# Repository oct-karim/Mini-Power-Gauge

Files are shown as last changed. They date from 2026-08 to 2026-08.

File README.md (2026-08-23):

<div align="center">

#  USB-C PCB Power Gauge

A simple PCB, functional and efficient. For monitoring current, voltage and power.







</div>

##  Overview

This simple power gauge, controlled by the ATmega328P microcontroller has a voltage range of 0-36V and a current range of 0-3A. 
The footprints have been chosen to be easy to solder. And the components are widely available.

## Features
-**Range** 0/36V & 0/3.5A    
-**16x2 Display**   
-**Sleep Mode**: Consumes less energy after 30s without mesuring voltage    
-**Warning LED**: Inform the user that the mesurements are reaching the max or a activated failsafe    
-**LCD Ping**: checks if the display is alive or faulty connection  
-**AVR Watchdog**: prevents the microcontroller to freeze for more than 2 sec    
-**I2C Failsafe**: checks if the  I2C communication is good to go    
-**Over range Failsafe**: if the mesurements are more than 36V or 3.5A it shuts down the sensor.    

##  Hardware Overview

| Component | Function |
| :--- | :--- |
| **ATmega328p** | Microcontroller handling data and display. |
| **INA226** | I2C current and power sensor. |
| **HY1602E** | Standard 16x2 character LCD display. |
| **PCF8574AT** | I2C expander to drive the LCD using less pins. |
| **USB-C Port** | Power input. |
| **ICSP Socket** | Firmware upload. |

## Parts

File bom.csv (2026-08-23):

Designator | Footprint | Quantity | Value | LCSC Part #
C1, C2, C3, C7, C8, C9 | 1210 | 6 | 100n
C4, C6 | 1210 | 2 | 22p
C5 | 1210 | 1 | 10µ
D1 | 1206 | 1 | RED
D2 | 1206 | 1 | GREEN
D3 | 1206 | 1 | BLUE
D4 | D_SMA | 1 | SMAJ5.0A
DS1 | WC1602A | 1 | HY1602E
FB1 | Ferrite_1210_3225Metric_Pad1.42x2.65mm_BigPads | 1 | 300Ω@100MHz
J1 | USB_C_Receptacle_GCT_USB4125-xx-x-0190_6P_TopMnt_Horizontal | 1 | USB_C_Receptacle_PowerOnly_6P
J2 | PinSocket_1x06_P2.54mm_Vertical | 1 | Conn_01x06_Socket
J3, J4 | ScrewTerminal_1x02_P3.5mm_Horizontal_Black | 2 | 3.5mm
J5 | PinSocket_1x16_P2.54mm_Vertical | 1 | Conn_01x16_Socket
Q1 | TO-92_Inline_Wide_EBC | 1 | 2N3904
R1, R2 | 1210 | 2 | 5.1K
R10, R9 | 1210 | 2 | 1k
R11 | R_Shunt_Ohmite_LVK12 | 1 | 0,02
R3 | 1210 | 1 | 10k
R4, R5, R6 | 1210 | 3 | 470
R7, R8 | 1210 | 2 | 4.7k
U1 | TQFP-32_7x7mm_P0.8mm | 1 | ATmega328P-A
U2 | SOIC-16W_7.5x10.3mm_P1.27mm | 1 | PCF8574AT
U3 | VSSOP-10_3x3mm_P0.5mm | 1 | INA226
X1 | Crystal_SMD_2012-2Pin_2.0x1.2mm_HandSoldering | 1 | 16MHz

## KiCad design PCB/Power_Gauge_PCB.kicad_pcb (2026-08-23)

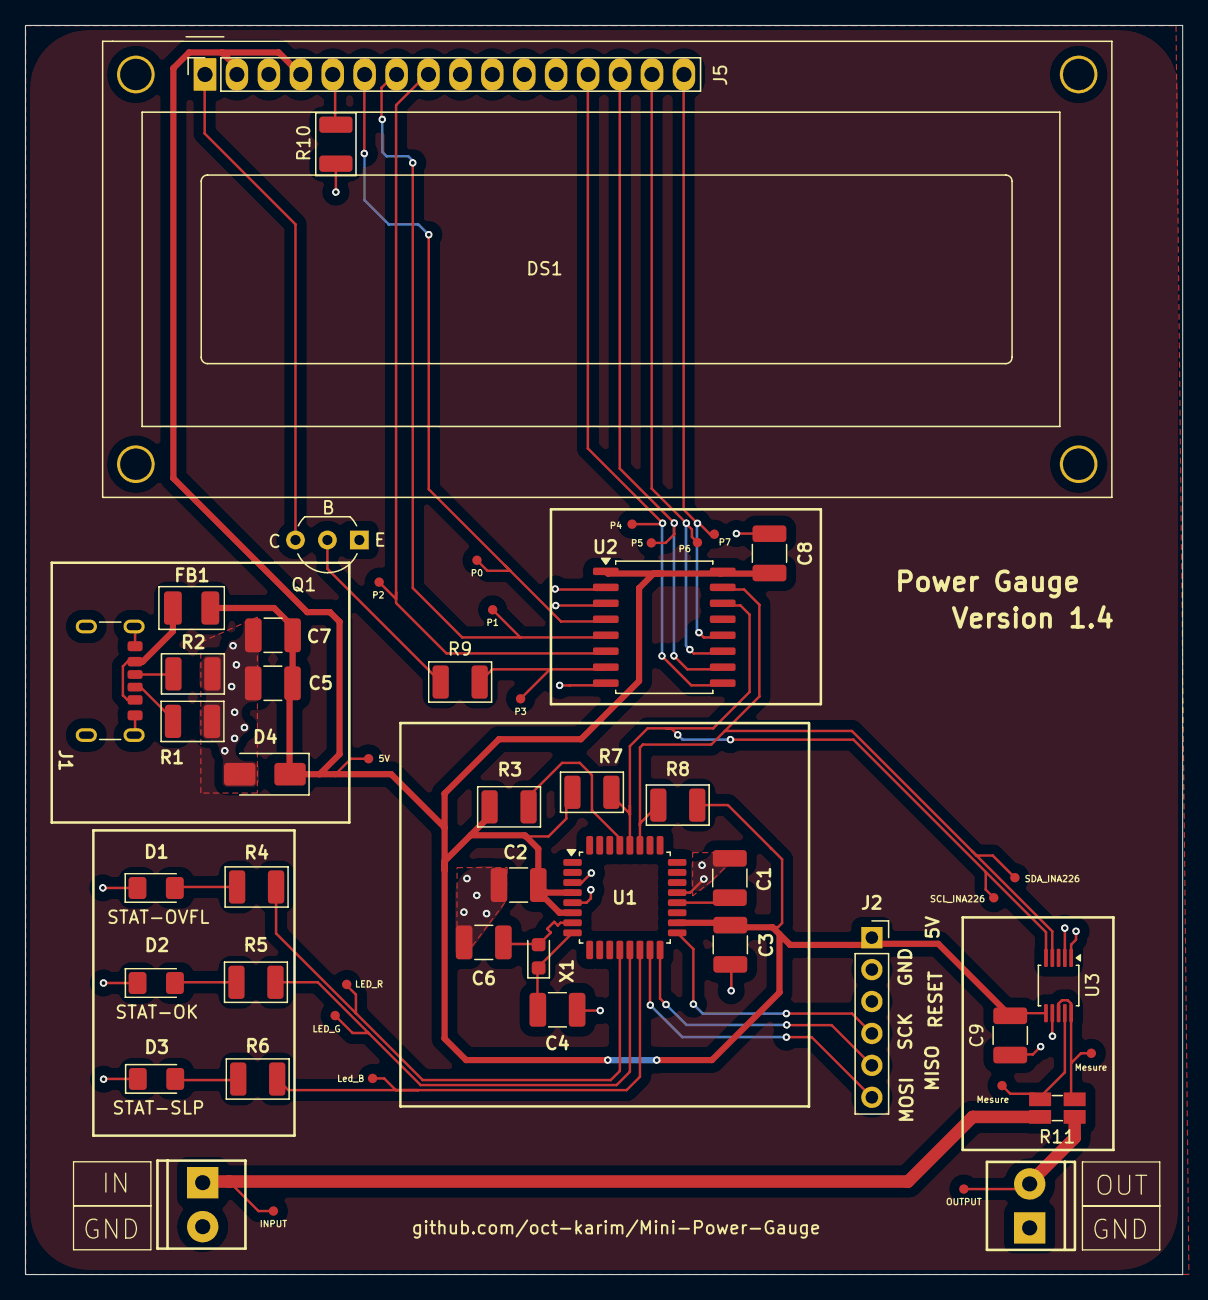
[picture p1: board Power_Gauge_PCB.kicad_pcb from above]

Board: 2 copper layers, 92.0 x 99.4 mm, 54 parts (0 on the bottom side), 35 nets.

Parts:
C1, C2, C3, C7, C8, C9: 100n; C_1210_3225Metric_Pad1.33x2.70mm_HandSolder
C4, C6: 22p; C_1210_3225Metric_Pad1.33x2.70mm_HandSolder
C5: 10µ; C_1210_3225Metric_Pad1.33x2.70mm_HandSolder
D1: RED; LED_1206_3216Metric_Pad1.42x1.75mm_HandSolder
D2: GREEN; LED_1206_3216Metric_Pad1.42x1.75mm_HandSolder
D3: BLUE; LED_1206_3216Metric_Pad1.42x1.75mm_HandSolder
D4: SMAJ5.0A; D_SMA
DS1: HY1602E; WC1602A
FB1: 300Ω@100MHz; Ferrite_1210_3225Metric_Pad1.42x2.65mm_BigPads
J1: USB_C_Receptacle_PowerOnly_6P; USB_C_Receptacle_GCT_USB4125-xx-x-0190_6P_TopMnt_Horizontal
J2: Conn_01x06_Socket; PinSocket_1x06_P2.54mm_Vertical
J3, J4: 3.5mm; ScrewTerminal_1x02_P3.5mm_Horizontal_Black
J5: Conn_01x16_Socket; PinSocket_1x16_P2.54mm_Vertical
Q1: 2N3904; TO-92_Inline_Wide_EBC
R1, R2: 5.1K; R_1210_3225Metric_Pad1.30x2.65mm
R3: 10k; R_1210_3225Metric_Pad1.30x2.65mm
R4, R5, R6: 470; R_1210_3225Metric_Pad1.30x2.65mm
R7, R8: 4.7k; R_1210_3225Metric_Pad1.30x2.65mm
R9, R10: 1k; R_1210_3225Metric_Pad1.30x2.65mm
R11: 0,02; R_Shunt_Ohmite_LVK12
TP1: LED_R; TestPoint-0.75mm
TP2: LED_G; TestPoint-0.75mm
TP3: Led_B; TestPoint-0.75mm
TP4: SCL_INA226; TestPoint-0.75mm
TP5: SDA_INA226; TestPoint-0.75mm
TP6: 5V; TestPoint-0.75mm
TP7: INPUT; TestPoint-0.75mm
TP8: OUTPUT; TestPoint-0.75mm
TP9: P1; TestPoint-0.75mm
TP10: P3; TestPoint-0.75mm
TP11: P5; TestPoint-0.75mm
TP12: P7; TestPoint-0.75mm
TP13: P0; TestPoint-0.75mm
TP14: P2; TestPoint-0.75mm
TP15: P4; TestPoint-0.75mm
TP16: P6; TestPoint-0.75mm
TP17, TP18: Mesure; TestPoint-0.75mm
U1: ATmega328P-A; TQFP-32_7x7mm_P0.8mm
U2: PCF8574AT; SOIC-16W_7.5x10.3mm_P1.27mm
U3: INA226; VSSOP-10_3x3mm_P0.5mm
X1: 16MHz; Crystal_SMD_2012-2Pin_2.0x1.2mm_HandSoldering

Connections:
5V: C2.2, C3.2, C5.1, C7.2, C8.2, C9.2, D4.1 (A1), DS1.2 (LEDA), DS1.4 (VDD), FB1.2, J2.1, J5.2, J5.4, R3.1, R7.2, R8.2, TP6.1 (1_1), U1.4 (VCC), U1.6 (VCC), U1.18 (AVCC), U2.1 (A0), U2.16 (VDD), U3.6 (VS)
/CONN_DISPLAY1: DS1.5 (Vo), J5.5, R10.2
/CONN_DISPLAY2: DS1.1 (LEDK), J5.1, Q1.3 (C)
GND: C1.1, C2.1, C3.1, C4.1, C5.2, C6.1, C7.1, C8.1, C9.1, D1.1 (K), D2.1 (K), D3.1 (K), D4.2 (A2), DS1.3 (VSS), J1.A12 (GND), J1.B12 (GND), J1.S1 (SHIELD), J2.2, J3.2, J4.1, J5.3, Q1.1 (E), R1.1, R2.2, R10.1, U1.3 (GND), U1.5 (GND), U1.21 (GND), U2.2 (A1), U2.3 (A2), U2.8 (GND), U3.1 (A1), U3.2 (A0), U3.7 (GND)
INPUT: J3.1, R11.1, TP7.1 (1_1)
MISO: J2.5, U1.16 (PB4)
MOSI: J2.6, U1.15 (PB3)
unnamed: D1.2 (A), R4.1
unnamed: D2.2 (A), R5.1
unnamed: D3.2 (A), R6.1
unnamed: FB1.1, J1.A9 (VBUS), J1.B9 (VBUS)
unnamed: J1.A5 (CC1), R2.1
unnamed: J1.B5 (CC2), R1.2
unnamed: Q1.2 (B), R9.1
unnamed: C1.2, U1.20 (AREF)
unnamed: R4.2, TP1.1 (1_1), U1.12 (PB0)
unnamed: R5.2, TP2.1 (1_1), U1.13 (PB1)
unnamed: R6.2, TP3.1 (1_1), U1.14 (PB2)
unnamed: C6.2, U1.7 (XTAL1/PB6), X1.2
unnamed: C4.2, U1.8 (XTAL2/PB7), X1.1
unnamed: R11.3, TP17.1 (1_1), U3.8 (Vbus), U3.10 (Vin+)
unnamed: R11.2, TP18.1 (1_1), U3.9 (Vin-)
OUTPUT: J4.2, R11.4, TP8.1 (1_1)
P0: DS1.6 (RS), J5.6, TP13.1 (1_1), U2.4 (P0)
P1: DS1.7 (R/~W), J5.7, TP9.1 (1_1), U2.5 (P1)
P2: DS1.8 (E), J5.8, TP14.1 (1_1), U2.6 (P2)
P3: R9.2, TP10.1 (1_1), U2.7 (P3)
P4: DS1.13 (DB4), J5.13, TP15.1 (1_1), U2.9 (P4)
P5: DS1.14 (DB5), J5.14, TP11.1 (1_1), U2.10 (P5)
P6: DS1.15 (DB6), J5.15, TP16.1 (1_1), U2.11 (P6)
P7: DS1.16 (DB7), J5.16, TP12.1 (1_1), U2.12 (P7)
RESET: J2.3, R3.2, U1.29 (~RESET/PC6)
SCK: J2.4, U1.17 (PB5)
SCL: R7.1, TP4.1 (1_1), U1.28 (PC5), U2.14 (SCL), U3.5 (SCL)
SDA: R8.1, TP5.1 (1_1), U1.27 (PC4), U2.15 (SDA), U3.4 (SDA)

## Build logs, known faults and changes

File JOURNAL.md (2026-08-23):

---
title: "USB-C PCB Power Gauge"
github: "oct-karim/Mini-Power-Gauge"
description: "A compact USB-C power monitor using an ATmega328P."
created_at: "2026-08-18"
---

<div align="center">

#  USB-C PCB POWER GAUGE 

---

## Introduction

Welcome to the journal for the **USB-C PCB Power Gauge**. 

This journal serves as a complete development log tracking the hardware design, schematic layout and firmware . The objective is to build a reliable USB-C meter capable of displaying real-time  voltage, current draw, and power consumption using an ATmega328P and dedicated I2C peripherals.

---
<div align="center">
  
##  Journal Entries Index

| Date | Log Title | Time Spent |
| :---: | :--- | :--- |
| [<ins>2026-08-18</ins>](#august-18-2026--Schematic-Design-and-datasheet-nightmare) | Schematic Design, PCB Layout and Firmware | 3h |
| [<ins>2026-08-19</ins>](#august-19-2026--PCB-Layout-and-Firmware) | Schematic Design, PCB Layout and Firmware | 4h |
| [<ins>2026-08-23</ins>](#august-23-2026--Rerouting) | Remade of the PCB layout| 1h |

---

# August 18, 2026:  Schematic Design and datasheet nightmare

<div align="center">

This is one of my firt pcb project. I already have experience in pcb layout and I2C communication but never used a 8-bit microcontroller. First i putted my objective clear: To mesure voltage and current. I didn't want a rp2040 or esp32 mcu. It's way overkill. I choose the ATmega328P. Simple and efficient. Searched online for datasheet and started routing and placing decoupling capacitors. Putted the USB-C receptacle and started adding bulking capacitors to smooth the power for the PCB. I placed a ferrite bead to block noise. I searched online for the perfect value and found 300 ohms and 600Mhz. I also choose a TVS Diode to protect it from voltage spikes. Then made the MCU footprint with it's 16MHz Crystal (Because it works at 5V and it's faster) some other decoupling capacitor and started connecting the MCU to the I2C expander. I, then addes three LED to make it more alive   
         
Then the nightmare begun... i had problems with the datasheet of the I2C Expander and how to connect it to the LCD. I searched for almost one hour and then asked to an ia lol. I thought it was intuitevly but no way:    
    This is the easy part, very simple to understand.   
            
      So in th beginning i routed all the "P" pins from the I2C expander to the DB for the LCD. But after countless reddit forums and datasheet i found out that it's wrong. The LCD needs only 4 pins to work so the other will be routed for the backlight. I then placed a connector for the LCD DIsplay beacuse it's not SMD.
      ²  
    I also added a BJT to regulate the backlight for the failsafe and sleepmode.  
        Then i placed the sensor and started calculating the resistance of the shunt resistor and with it's max shunt rating of 82mV and my current rangr of 3A i placed a 0.02 ohm shunt resistor.       
                
                In the end i placed the ICSP socket to programm the ATmega beacuse it doesn't have a USB interface    
                        
                        And placed the INPUT/OUTPUT of the load to mesure. I used screw terminals    
                                
                                That's the end for today, i actually spent 3h+ 2h of research and datasheet anaalysis. Anyway, next time i will start to route the PCB layout and make the firmware.
  ## Final Schematics 
      
        Total time spent: 3h+2h of research

---

# August 19, 2026:  PCB Layout and Firmware

<div align="center">
Today i made the PCB Layout,i had some difficulties while routing because the weird footprint of some compnents. But did a good job in the end:
        
        I started routing the USB-C Section, i didn't have any problem        
            
          I choose for a GND pouring because it's good practice to put two vias per decoupling/Bulking capcitor and made a pour for the 5V.
          Then i made the LED status:         OVFL=Overflow (max voltage/current range or failsafe) OK=Good function of the PCB  SLP=Sleep mode  
          Then i made the MCU + I2C expander layout      had some problem here i had to make compromise between soldering, density and decoupling signal bridges.
              Then the bottom part with the ICSP header and the sensor:     
                  In the end i made the layout for the LCD Display with the dupont connector    
                      
                      I had to make vias bridge for the signal because they crossed. All caused by the weird foorprint of the I2C expander.
                      This is the final result:     
      

  Then i started to make the code. I used C++ and i will uplaod it with a USBasp Uploader (3$ on aliexpress) I searched a lot  on the internet for the libraries and to how to make the failsafes. In the end i'm pretty satisfied. But i think that the firmware needs some refining. 

# August 23, 2026:  Rerouting

Today i made the PCB design layout more compact and efficient without touching the easy-to-solder footprints. I also added testpoint. This is the final result:    
        
        This is the final render:     
          

---

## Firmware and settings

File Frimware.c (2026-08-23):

#include <Wire.h>
#include <LiquidCrystal_I2C.h>
#include <INA226_WE.h>
#include <avr/wdt.h>

// ADDRESSES
const uint8_t I2C_LCD_ADDRESS = 0x3B;
const uint8_t INA226_ADDRESS = 0x40;

// DEFINITIONS
const uint8_t LED_RED_PIN = 8;   // PB0
const uint8_t LED_GREEN_PIN = 9; // PB1
const uint8_t LED_BLUE_PIN = 10; // PB2
LiquidCrystal_I2C lcd(I2C_LCD_ADDRESS, 16, 2);
INA226_WE ina226 = INA226_WE(INA226_ADDRESS);
// Stby function
unsigned long lastValidReadTime = 0;
const unsigned long STANDBY_TIMEOUT_MS = 30000; //
bool isStandby = false;

void setup()
{
    wdt_disable();
    Serial.begin(115200);
    Wire.begin();
    pinMode(LED_RED_PIN, OUTPUT);
    pinMode(LED_GREEN_PIN, OUTPUT);
    pinMode(LED_BLUE_PIN, OUTPUT);
    digitalWrite(LED_GREEN_PIN, LOW);
    digitalWrite(LED_RED_PIN, LOW);
    digitalWrite(LED_BLUE_PIN, LOW);

    // FAILSAFE Check LCD
    Wire.beginTransmission(I2C_LCD_ADDRESS);
    if (Wire.endTransmission() != 0)
    {
        Serial.println(F("ERROR: LCD (PCF8574AT) not found."));
        digitalWrite(LED_RED_PIN, HIGH);
        while (1);
    }

    lcd.init();
    lcd.backlight();
    lcd.setCursor(0, 0);
    lcd.print(F("System Boot"));

    // FAILSAFE 2: Check INA226
    if (!ina226.init())
    {
        Serial.println(F("ERROR: INA226 not found."));
        lcd.setCursor(0, 1);
        lcd.print(F("INA226 FAIL"));
        digitalWrite(LED_RED_PIN, HIGH);
        while (1);
    }
//shunt resistor
    ina226.setResistorRange(0.02, 3.2);
    ina226.waitUntilConversionCompleted();
    lcd.clear();
    lastValidReadTime = millis();
    wdt_enable(WDTO_2S); // Watchdog
}

void loop()
{
    wdt_reset();
    //Calculations
    float busVoltage_V = ina226.getBusVoltage_V();
    float current_A = ina226.getCurrent_mA();
    float current_A = current_mA / 1000.0; 
    bool validMeasurement; // Hysteresis
if (isStandby) {
    validMeasurement = (busVoltage_V > 0.2); // Higher range wake up
} else {
    validMeasurement = (busVoltage_V > 0.1); // Lower range to stay awake
}

    if (validMeasurement)
    {
        lastValidReadTime = millis();

        if (isStandby)
        {
            isStandby = false;
            lcd.backlight();
            lcd.clear();
        }
        // FAILSAFE Shuts down INA226
        if (busVoltage_V >= 36.0 || current_A > 3.5)
        {
            ina226.powerDown();
            digitalWrite(LED_RED_PIN, HIGH);
            digitalWrite(LED_GREEN_PIN, LOW);
            digitalWrite(LED_BLUE_PIN, LOW);
            lcd.clear();
            lcd.setCursor(0, 0);
            lcd.print(F("OVERLOAD"));
            lcd.setCursor(0, 1);
            lcd.print(F("SENSOR SHUTDOWN"));
            Serial.println(F("Over-Range. Sensor powered down."));

            // Blocks system 
            while (1)
            {
                wdt_reset(); // watchdog 
                delay(100);
            }
        }
        else
        {
            // STAT_OK
            digitalWrite(LED_RED_PIN, LOW);
            digitalWrite(LED_GREEN_PIN, HIGH);
            digitalWrite(LED_BLUE_PIN, LOW);
        }
        // LCD
        lcd.setCursor(0, 0);
        lcd.print(F("V: "));
        lcd.print(busVoltage_V, 2);
        lcd.print(F("V       "));
        lcd.setCursor(0, 1);
        lcd.print(F("I: "));
        lcd.print(current_mA, 1);
        lcd.print(F("mA      "));
    }
  else
{
    // STANDBY 
    if (millis() - lastValidReadTime > STANDBY_TIMEOUT_MS)
    {
        if (!isStandby)
        {
            isStandby = true;
            lcd.noBacklight();
            lcd.clear();
            lcd.setCursor(0, 0);
            lcd.print(F("Standby"));
            digitalWrite(LED_BLUE_PIN, HIGH);
            digitalWrite(LED_GREEN_PIN, LOW);
            digitalWrite(LED_RED_PIN, LOW);
        }
    }
}
    delay(500);
}
// Made by oct-karim
// 19/08/2026    V1.4

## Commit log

2026-08-18 Create journal for USB-C PCB Power Gauge project
    Added a development journal for the USB-C PCB Power Gauge project, including an introduction, journal entries index, and initial entry detailing schematic design and hardware components.
2026-08-19 Power_Gauge_PCB schematics
    [Power_Gauge_PCB.kicad_sch]
2026-08-19 Create Power_Gauge_PCB
2026-08-19 Power Gauge Schematics
    [Power_Gauge_PCB.kicad_sch]
2026-08-19 Rename Power_Gauge_PCB.kicad_sch to Power_Gauge_PCB Schematics
2026-08-19 Rename Power_Gauge_PCB.kicad_pcb to Power_Gauge pcb
2026-08-19 Rename Power_Gauge_PCB Schematics to Power_Gauge Schematics
2026-08-19 Rename Power_Gauge pcb to Power_Gauge Pcb
2026-08-19 Create Schematics
2026-08-19 Revise journal entries for USB-C PCB Power Gauge
    Updated journal entries to reflect changes in project objectives and time spent on tasks. Revised sections for clarity and corrected errors in the document.
2026-08-21 Rename bom.csv-JLCPCB BOM Tool (1).xls to bom.csv-JLCPCB
2026-08-21 Rename bom.csv-JLCPCB BOM Tool (1) (1).csv to BOM.csv
    [BOM.csv, bom.csv-JLCPCB BOM Tool (1) (1).csv]
2026-08-23 Add log entry for PCB rerouting on August 23, 2026
    Added a new log entry for PCB rerouting on August 23, 2026, detailing improvements made to the layout and the addition of test points.
2026-08-23 PCB design
2026-08-23 BOM list
    [bom.csv]
2026-08-23 Update bom.csv
    Updated BOM file to correct formatting and add missing entries.
    [bom.csv]
2026-08-23 Fix issues and improve INA226 handling in firmware
    [Frimware.c]
